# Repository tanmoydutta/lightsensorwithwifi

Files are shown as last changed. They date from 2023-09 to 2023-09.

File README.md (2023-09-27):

<h1>ESP32-C3 based Light sensor</h1>

<h2>Description</h2>
This tiny module is designed around Espressief's ESP32-C3 System On a Chip. Purpose of this module is simple, measure the ambient or incident
light and communicate the reading through the chip's built-in WiFi interface. It uses AMS OSRAM TSL2591 sensor to measure the incident light.

Primary challenge has been to design an RF (Radio Frequency) optimised PCB (Printed Circuit Board) to accommodate this electronics. This designed is optimised for WiFi 2.4GHz and features a
chip antenna (Ignion's NN01-102) to minimize the board size (35mm x 20mm).

The PCB has been designed as per the hardware design guidelines from Espressief with one noticeable deviation on the thickness of the PCB (1.6mm instead of the recommended ~0.8mm)

RF part of the board has been tested with a VNA (Vector Network Analyser) and has been optimized with the help of a matching Pi-network. 
Antenna traces are also designed based upon the datasheet specification and recommended trace pattern.

This hardware has been certified with Open Source Hardware Association


<h2>The Module</h2>
End result of the PCB is a 4 layer design and manufactured with the help of JLC PCB (https://jlcpcb.com) which according to their documentation has a 
dielectric constant of 4.5 for FR-4 type material. 

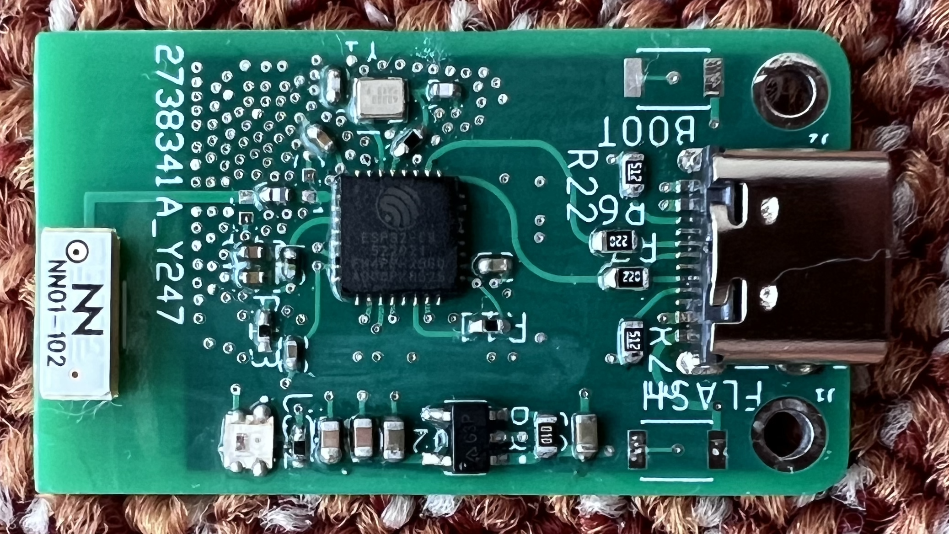
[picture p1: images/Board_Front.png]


The light sensor is mounted on the back side of the board as depicted below -

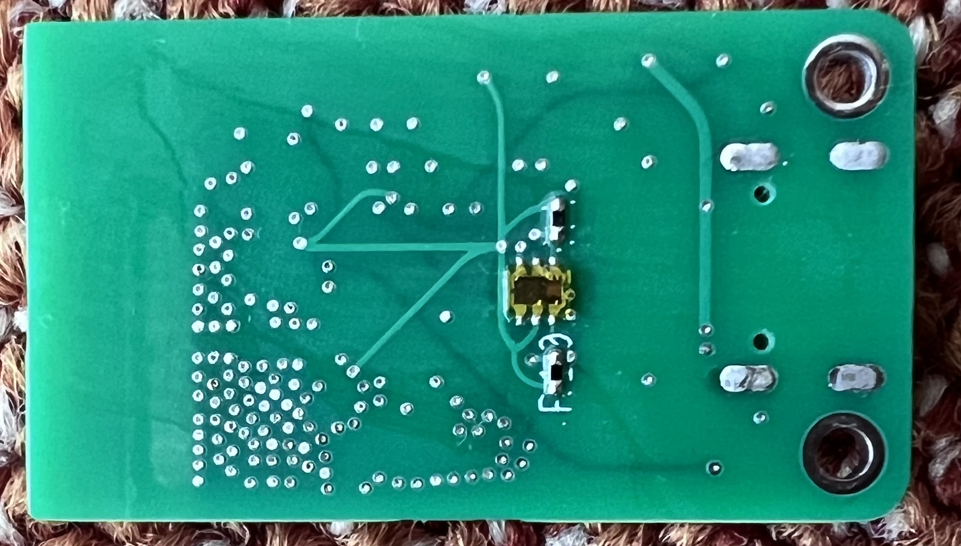
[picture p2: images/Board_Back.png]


Here is a size reference for the end module - 



<h2>Enclosure</h2>
I went ahead and also designed a 3D model for the housing of this module for application - 

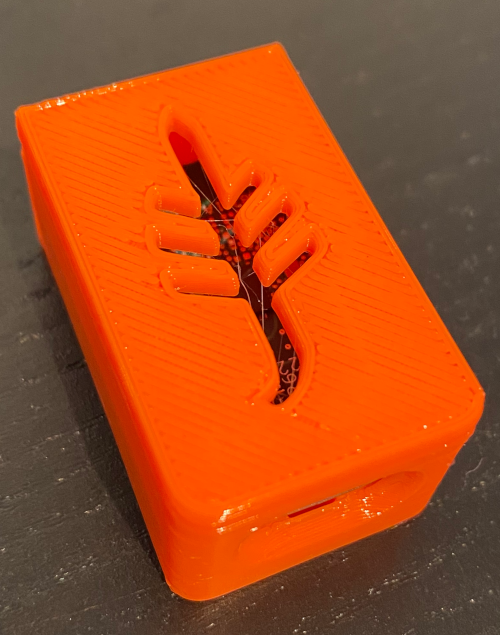
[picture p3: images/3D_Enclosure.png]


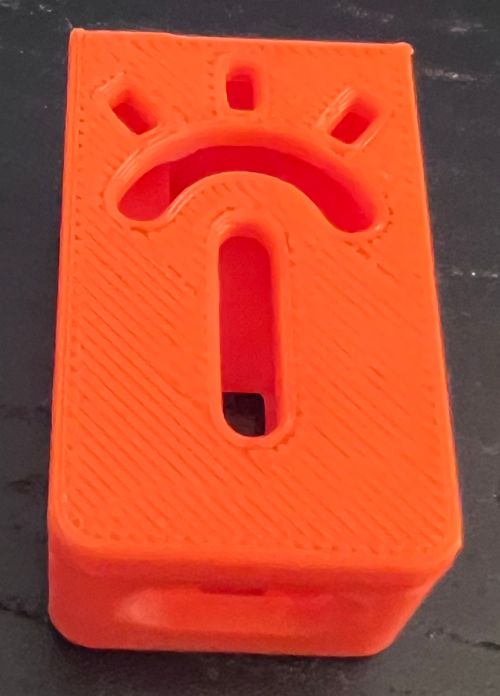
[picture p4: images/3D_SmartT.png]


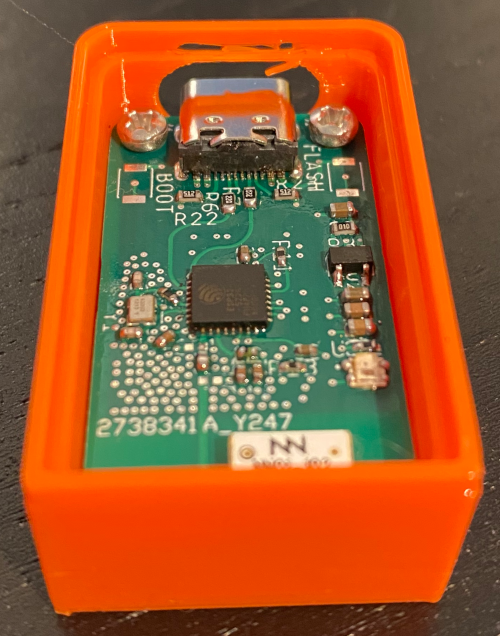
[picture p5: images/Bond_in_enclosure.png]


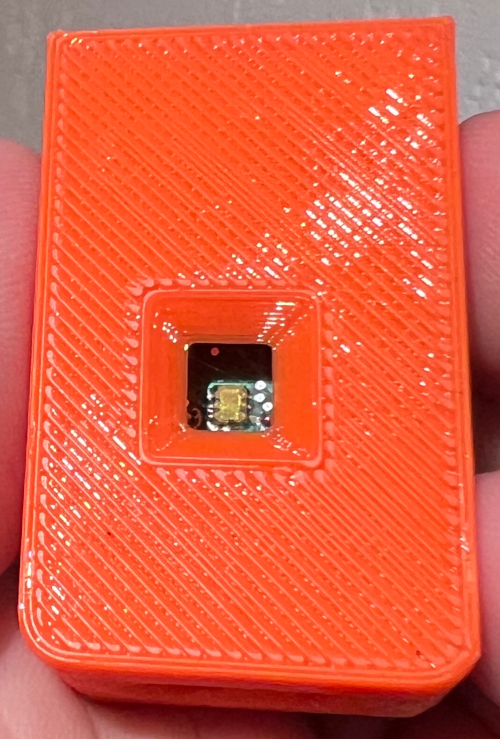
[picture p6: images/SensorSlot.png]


<h2>Programming</h2>
Add your own firmware and code to make use of the built-in sensor and indicator. This module can be programmed using Arduino or ESP-IDF IDE. This module has a 
close resemblance with LOLIN C3 Mini or Adafruit C3 QTPy, hence those core board definitions are compatible with this module.

<h2>Design and Architecture</h2>
Below is the System Context for this module highlighting 
the interfaces and interactions with this module. 

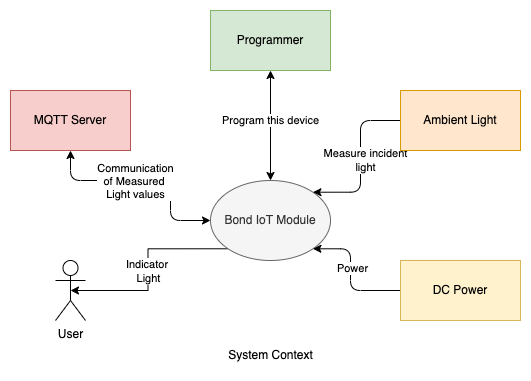
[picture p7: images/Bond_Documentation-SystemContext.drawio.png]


Also a blown up building block of functionality within.

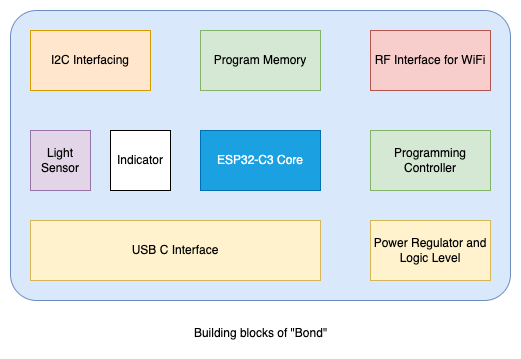
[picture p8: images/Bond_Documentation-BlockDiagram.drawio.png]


<h2>Applications</h2>
One implementation that I personally use this module is for the purpose of controlling the lights on my balcony and eventually also festive lights during Christmas.
Following a possible application diagram -

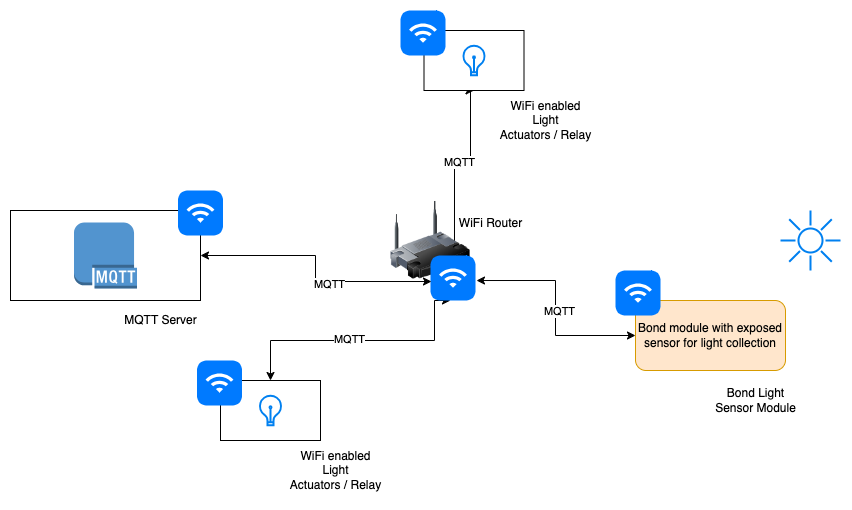
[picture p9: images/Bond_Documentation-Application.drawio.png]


<h2>Open Source Hardware</h2>
This board is an OSHWA approved design: <a href="https://certification.oshwa.org/nl000015.html">NL000015</a>



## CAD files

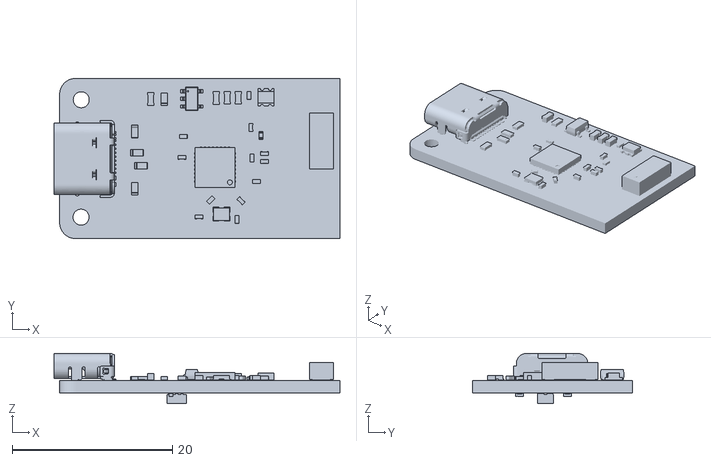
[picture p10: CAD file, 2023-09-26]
3D_Files/Bond.stl
35.7 x 20.0 x 6.26

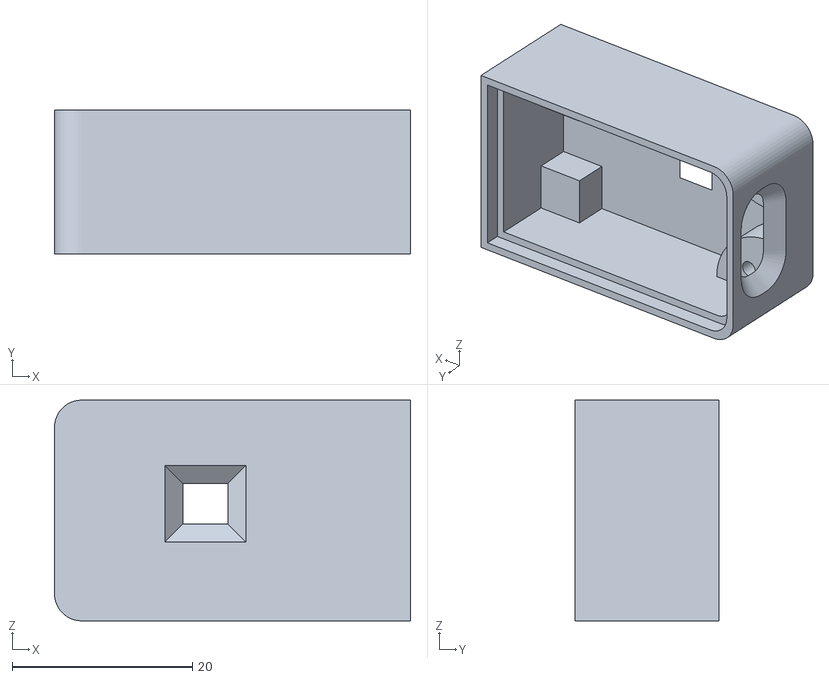
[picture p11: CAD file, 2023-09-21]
3D_Files/BondBox.stl
39.5 x 16.0 x 24.5

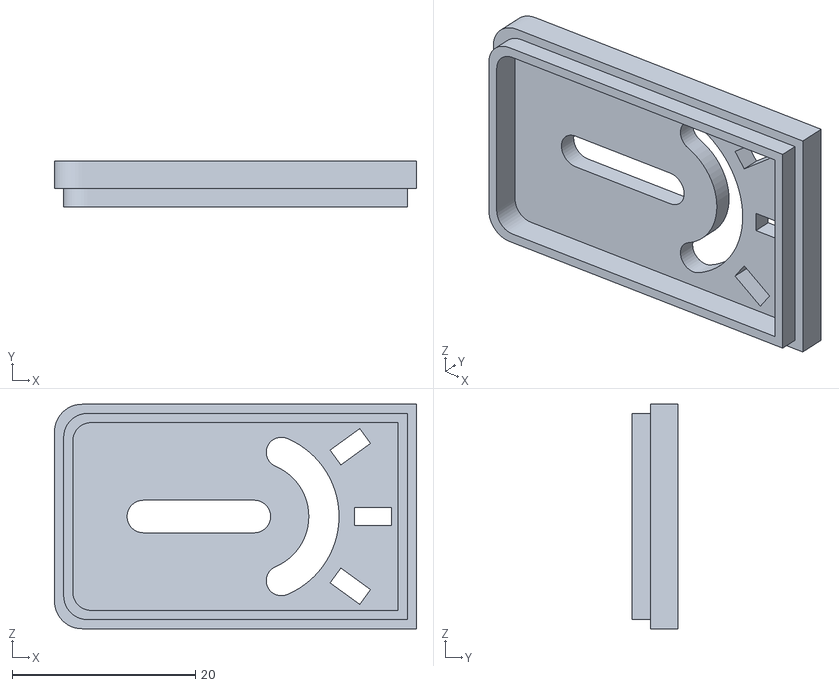
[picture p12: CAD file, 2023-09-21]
3D_Files/BondLidSmartT.stl
39.5 x 5.00 x 24.5

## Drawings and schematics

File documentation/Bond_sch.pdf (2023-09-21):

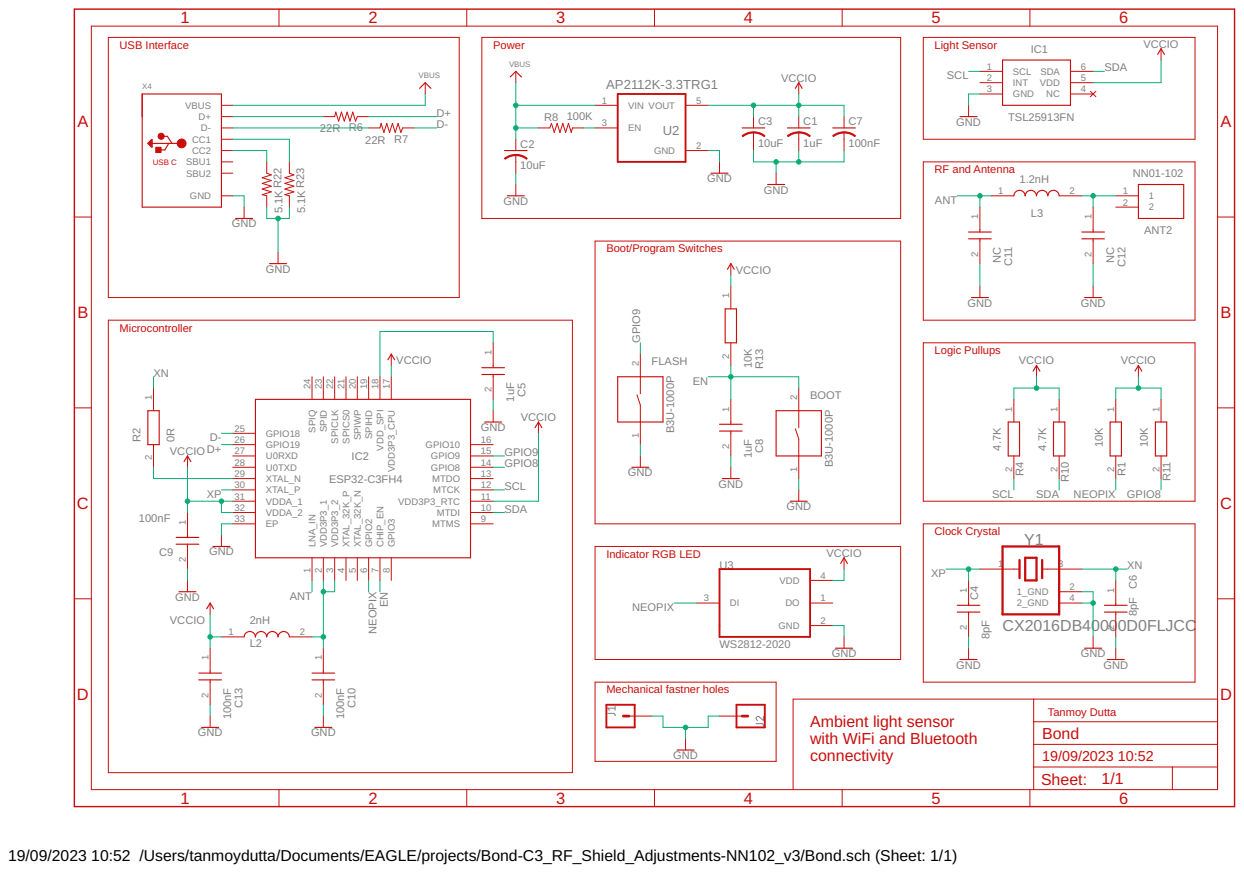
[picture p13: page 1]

Ambient light sensor
with WiFi and Bluetooth
connectivity

19/09/2023 10:52 /Users/tanmoydutta/Documents/EAGLE/projects/Bond-C3_RF_Shield_Adjustments-NN102_v3/Bond.sch (Sheet: 1/1)

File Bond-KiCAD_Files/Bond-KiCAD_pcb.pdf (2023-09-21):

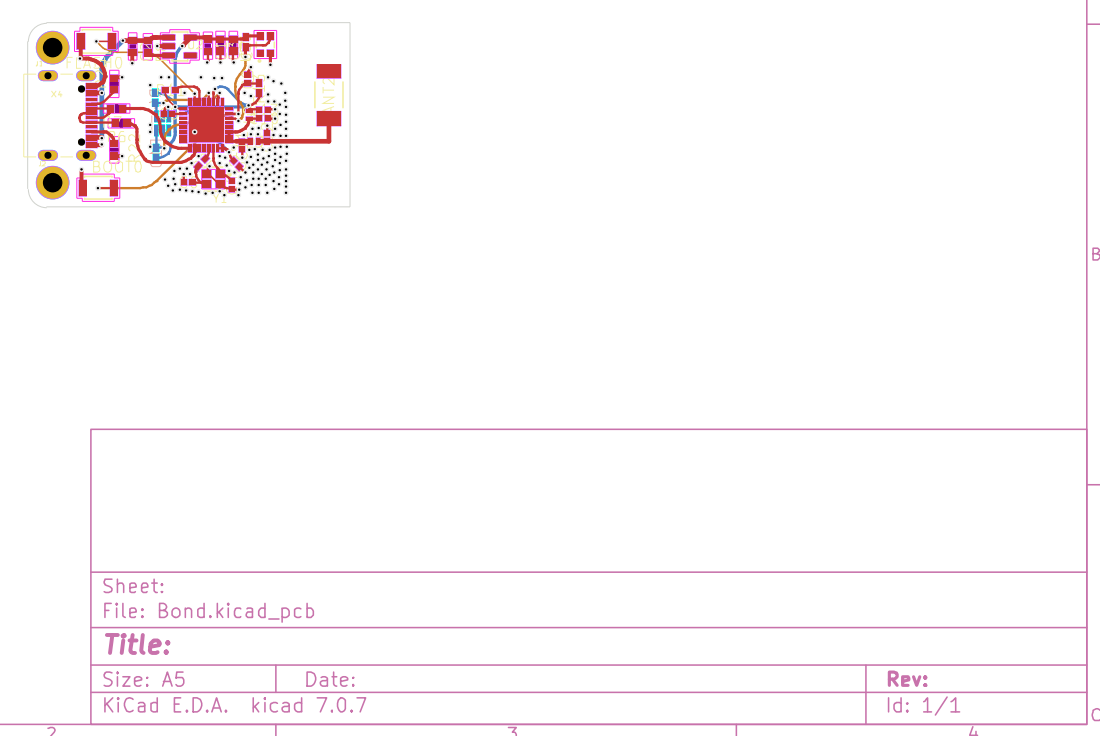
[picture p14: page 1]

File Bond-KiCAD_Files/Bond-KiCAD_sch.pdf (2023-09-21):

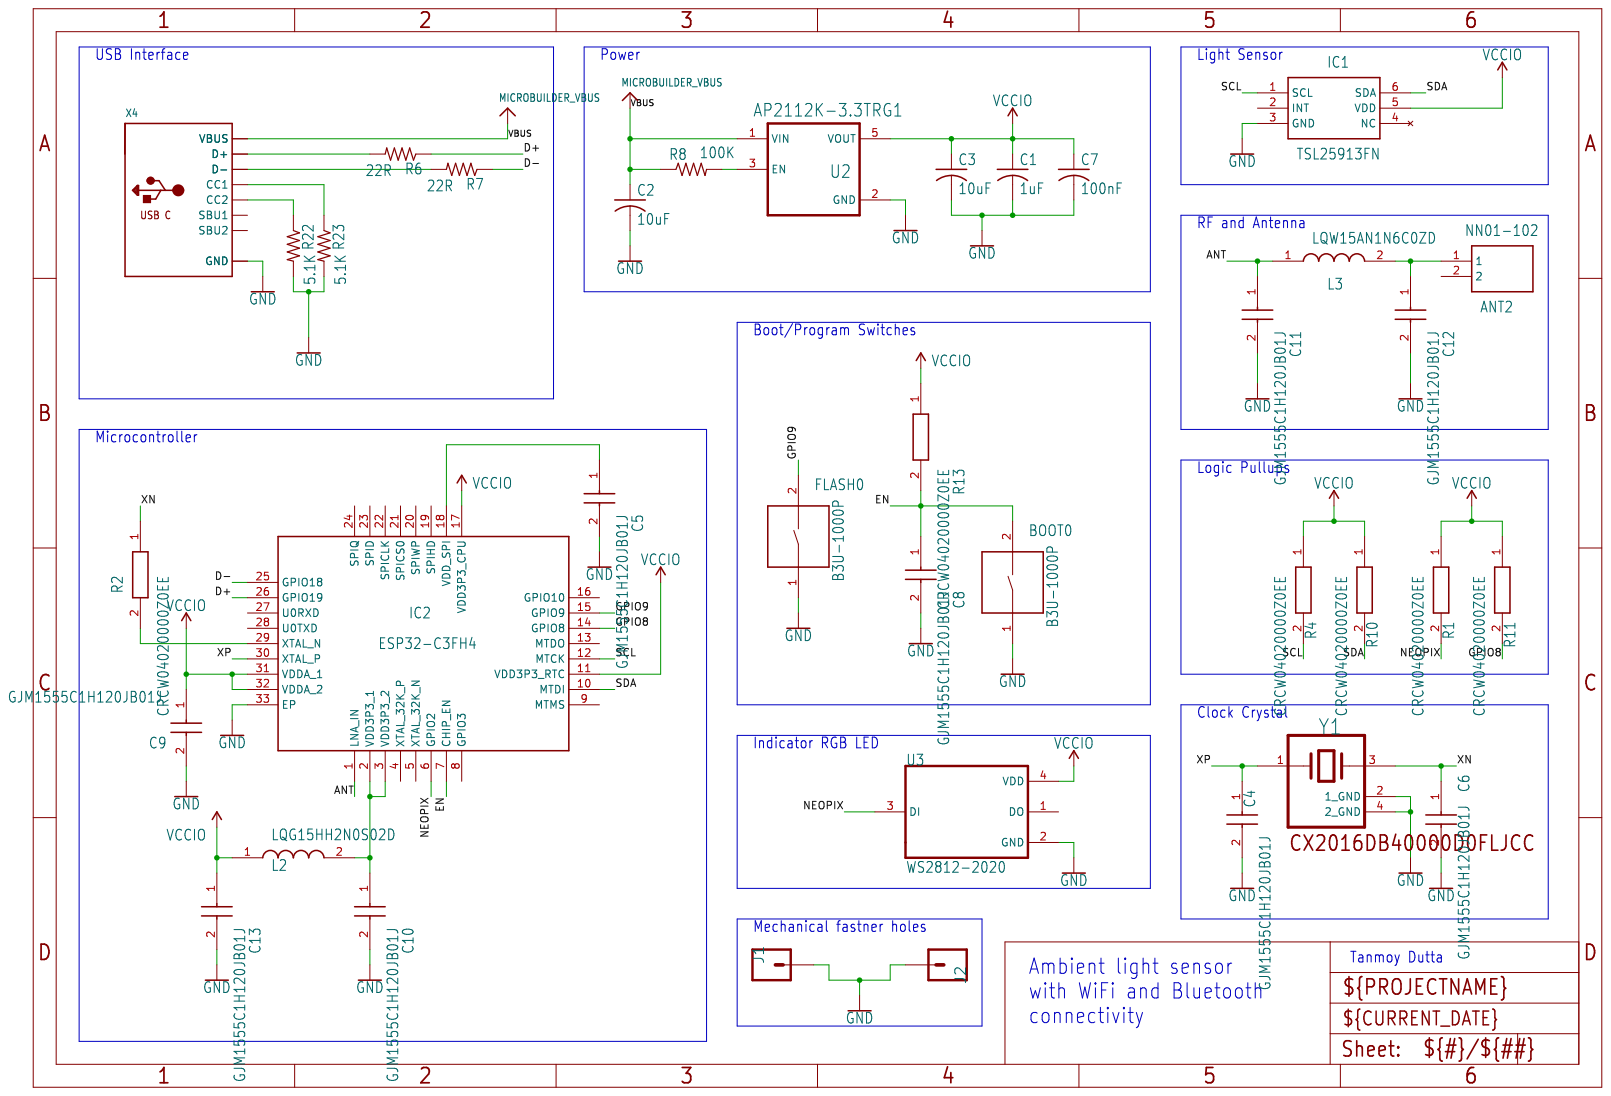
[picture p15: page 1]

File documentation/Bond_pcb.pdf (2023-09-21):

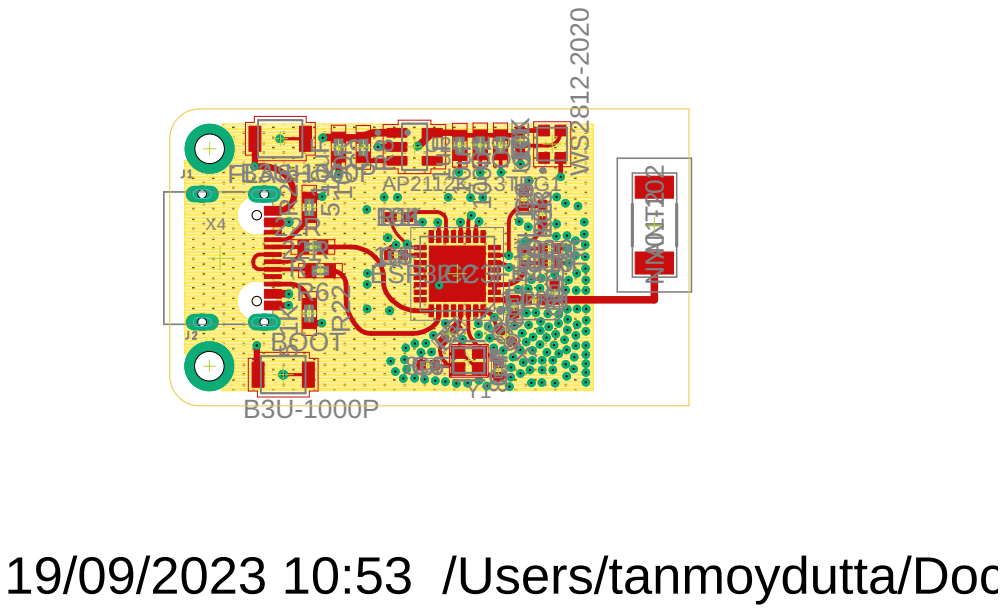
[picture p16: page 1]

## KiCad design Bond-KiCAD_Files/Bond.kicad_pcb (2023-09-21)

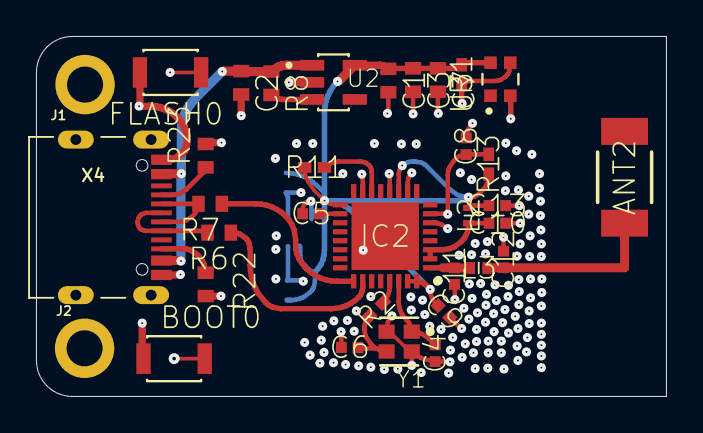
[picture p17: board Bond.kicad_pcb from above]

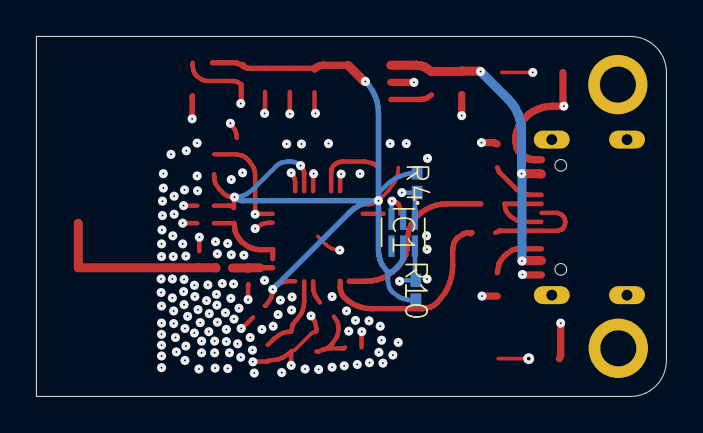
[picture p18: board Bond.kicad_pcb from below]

Board: 4 copper layers, 35.0 x 20.0 mm, 37 parts (3 on the bottom side), 23 nets.

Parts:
ANT2: NN01-102; NN01102
BOOT0: B3U-1000P; SW_B3U-1000P
C1: 1uF; C0402
C2, C3: 10uF; C0402
C4, C6: 8pF; CAPC1005X55N
C5, C8: 1uF; CAPC1005X55N
C7: 100nF; C0402
C9, C10, C13: 100nF; CAPC1005X55N
C11, C12: NC; CAPC1005X55N
FLASH0: B3U-1000P; SW_B3U-1000P
IC1: TSL25913FN
IC2: ESP32-C3FH4; QFN50P500X500X90-33N
J1, J2: 1X01_2MM
L2: 2nH; LQG15WH0N7B02D
L3: 1.2nH; LQW15CNR20J00B
R1, R11, R13: 10K; RESC1005X40N
R2: 0R; RESC1005X40N
R4, R10: 4.7K; RESC1005X40N
R6, R7: 22R; R0402
R8: 100K; R0402
R22, R23: 5.1K; R0402
U2: AP2112K-3.3TRG1; SOT95P285X140-5N
U3: WS2812-2020; LED_WS2812-2020
X4: MICROBUILDER_USB_C_CUSB31-CFM2AX-01-X
Y1: 40MHz; KYOCERA_INTERNATIONAL_INC._ELECTRONIC_COMPONENTS_CX2016DB40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

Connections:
ANT: C11.1, IC2.1, L3.1
D+: IC2.26, R6.1
D-: IC2.25, R7.1
EN: BOOT0.2, C8.1, IC2.7, R13.2
GND: BOOT0.1, C1.2, C2.2, C3.2, C4.2, C5.2, C6.2, C7.2, C8.2, C9.2, C10.2, C11.2, C12.2, C13.2, FLASH0.1, IC1.3, IC2.33, J1.1, J2.1, R22.2, R23.2, U2.2, U3.2, X4.A1B12, X4.B1A12, Y1.2, Y1.4
GPIO8: IC2.14, R11.2
GPIO9: FLASH0.2, IC2.15
unnamed: C5.1, IC2.18
unnamed: ANT2.1, C12.1, L3.2
unnamed: C10.1, IC2.2, IC2.3, L2.2
unnamed: IC2.29, R2.2
unnamed: R22.1, X4.B5
unnamed: R23.1, X4.A5
unnamed: R7.2, X4.A7, X4.B7
unnamed: R6.2, X4.A6, X4.B6
unnamed: R8.2, U2.3
NEOPIX: IC2.6, R1.2, U3.3
SCL: IC1.1, IC2.12, R4.2
SDA: IC1.6, IC2.10, R10.2
VBUS: C2.1, R8.1, U2.1, X4.A4B9, X4.B4A9
VCCIO: C1.1, C3.1, C7.1, C9.1, C13.1, IC1.5, IC2.11, IC2.17, IC2.31, IC2.32, L2.1, R1.1, R4.1, R10.1, R11.1, R13.1, U2.5, U3.4
XN: C6.1, R2.1, Y1.3
XP: C4.1, IC2.30, Y1.1

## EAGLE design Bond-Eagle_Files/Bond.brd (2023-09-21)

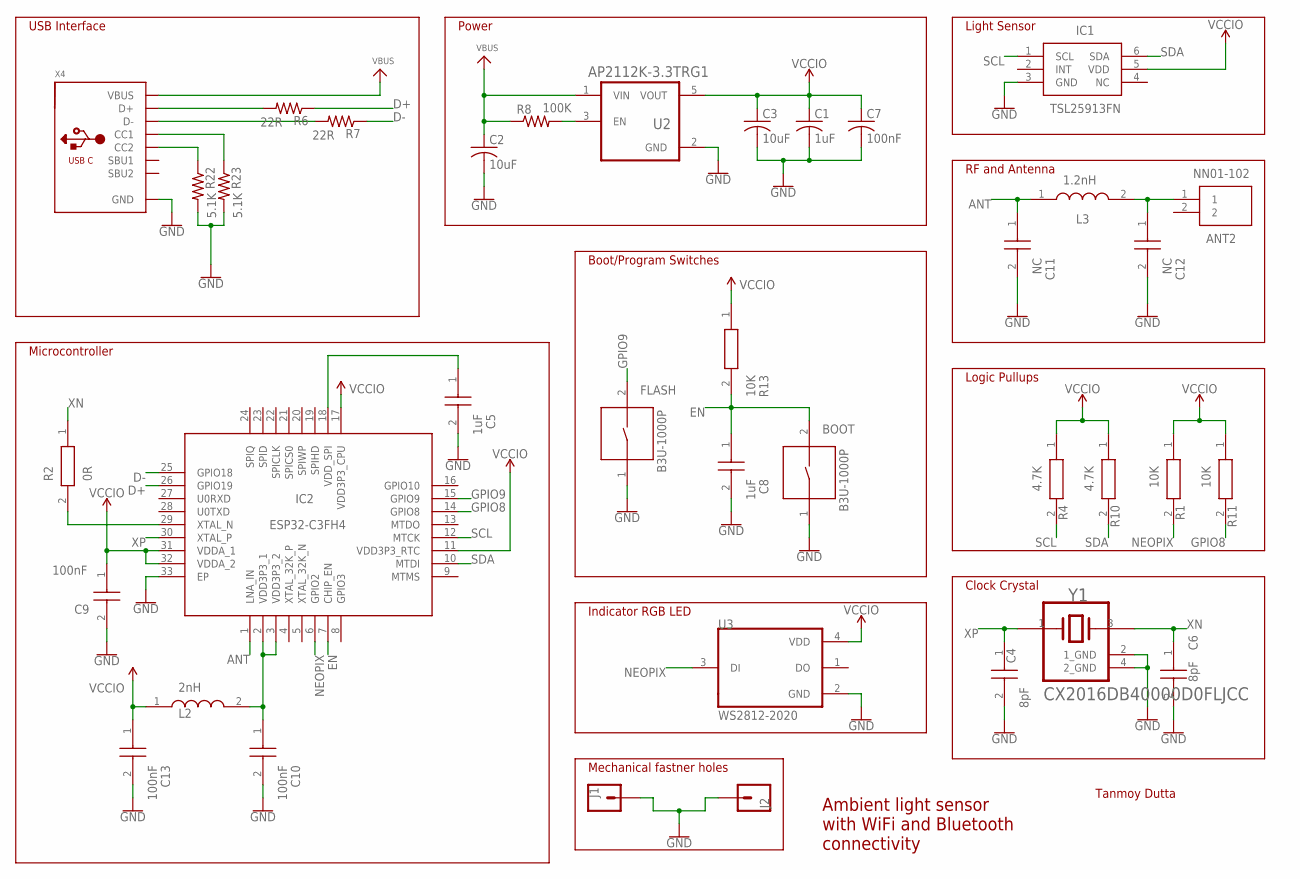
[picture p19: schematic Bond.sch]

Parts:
ANT2: NN01-102; NN01102
BOOT: B3U-1000P; SW_B3U-1000P
C1: 1uF; C0402
C2, C3: 10uF; C0402
C4, C6: 8pF; CAPC1005X55N
C5, C8: 1uF; CAPC1005X55N
C7: 100nF; C0402
C9, C10, C13: 100nF; CAPC1005X55N
C11, C12: NC; CAPC1005X55N
FLASH: B3U-1000P; SW_B3U-1000P
IC1: TSL25913FN
IC2: ESP32-C3FH4; QFN50P500X500X90-33N
J1, J2: CONN_01PTH_2MM; 1X01_2MM
L2: 2nH; LQG15WH0N7B02D
L3: 1.2nH; LQW15CNR20J00B
R1, R11, R13: 10K; RESC1005X40N
R2: 0R; RESC1005X40N
R4, R10: 4.7K; RESC1005X40N
R6, R7: 22R; R0402
R8: 100K; R0402
R22, R23: 5.1K; R0402
U2: AP2112K-3.3TRG1; SOT95P285X140-5N
U3: WS2812-2020; LED_WS2812-2020
X4: MICROBUILDER_USB_C; MICROBUILDER_USB_C_CUSB31-CFM2AX-01-X
Y1: 40MHz; KYOCERA_INTERNATIONAL_INC._ELECTRONIC_COMPONENTS_CX2016DB40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

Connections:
ANT: C11.1, IC2.1 (LNA_IN), L3.1
D+: IC2.26 (GPIO19), R6.1
D-: IC2.25 (GPIO18), R7.1
EN: BOOT.2, C8.1, IC2.7 (CHIP_EN), R13.2
GND: BOOT.1, C1.2, C2.2, C3.2, C4.2, C5.2, C6.2, C7.2, C8.2, C9.2, C10.2, C11.2, C12.2, C13.2, FLASH.1, IC1.3 (GND), IC2.33 (EP), J1.1, J2.1, R22.2, R23.2, U2.2 (GND), U3.2 (GND), X4.A1B12 (GND), X4.B1A12 (GND), Y1.2 (1_GND), Y1.4 (2_GND)
GPIO8: IC2.14 (GPIO8), R11.2
GPIO9: FLASH.2, IC2.15 (GPIO9)
unnamed: C5.1, IC2.18 (VDD_SPI)
unnamed: ANT2.1, C12.1, L3.2
unnamed: C10.1, IC2.2 (VDD3P3_1), IC2.3 (VDD3P3_2), L2.2
unnamed: IC2.29 (XTAL_N), R2.2
unnamed: R22.1, X4.B5 (CC2)
unnamed: R23.1, X4.A5 (CC1)
unnamed: R7.2, X4.A7 (D-), X4.B7 (D-)
unnamed: R6.2, X4.A6 (D+), X4.B6 (D+)
unnamed: R8.2, U2.3 (EN)
NEOPIX: IC2.6 (GPIO2), R1.2, U3.3 (DI)
SCL: IC1.1 (SCL), IC2.12 (MTCK), R4.2
SDA: IC1.6 (SDA), IC2.10 (MTDI), R10.2
VBUS: C2.1, R8.1, U2.1 (VIN), X4.A4B9 (VBUS), X4.B4A9 (VBUS)
VCCIO: C1.1, C3.1, C7.1, C9.1, C13.1, IC1.5 (VDD), IC2.11 (VDD3P3_RTC), IC2.17 (VDD3P3_CPU), IC2.31 (VDDA_1), IC2.32 (VDDA_2), L2.1, R1.1, R4.1, R10.1, R11.1, R13.1, U2.5 (VOUT), U3.4 (VDD)
XN: C6.1, R2.1, Y1.3
XP: C4.1, IC2.30 (XTAL_P), Y1.1

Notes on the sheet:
Microcontroller
USB Interface
Power
Boot/Program Switches
Light Sensor
RF and Antenna
Indicator RGB LED
Mechanical fastner holes
Clock Crystal
Logic Pullups
Ambient light sensor with WiFi and Bluetooth connectivity
Tanmoy Dutta

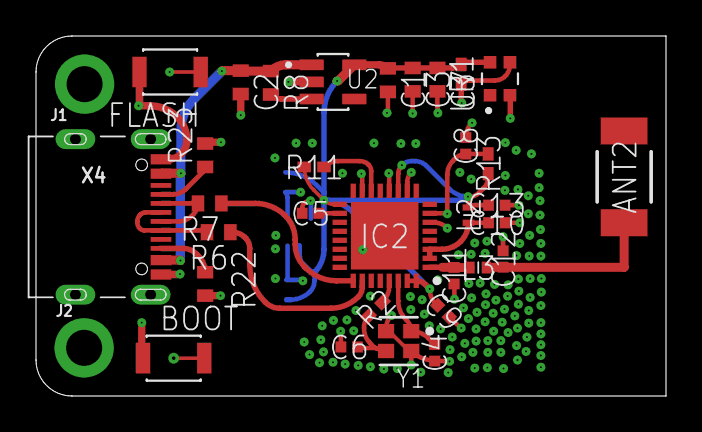
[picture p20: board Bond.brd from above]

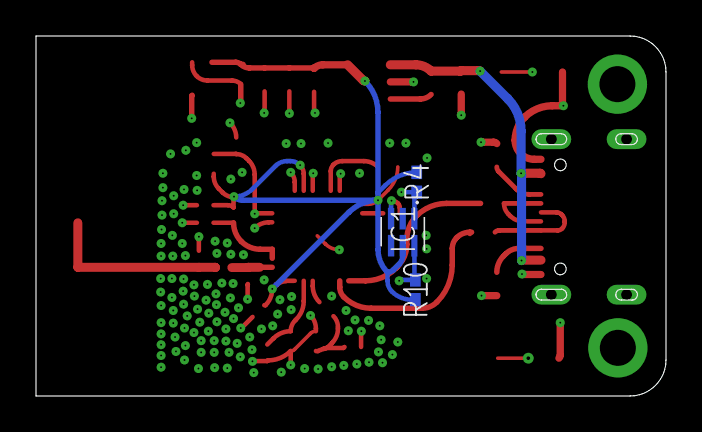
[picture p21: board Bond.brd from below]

Board: 4 copper layers, 35.0 x 20.0 mm, 37 parts (3 on the bottom side), 23 nets.

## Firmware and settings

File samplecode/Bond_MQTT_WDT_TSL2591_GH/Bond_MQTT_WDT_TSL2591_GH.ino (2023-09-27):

/***************************************************
  Adafruit MQTT Library ESP32 Adafruit IO SSL/TLS example

  Use the latest version of the ESP32 Arduino Core:
    https://github.com/espressif/arduino-esp32

  Works great with Adafruit Huzzah32 Feather and Breakout Board:
    https://www.adafruit.com/product/3405
    https://www.adafruit.com/products/4172

  Adafruit invests time and resources providing this open source code,
  please support Adafruit and open-source hardware by purchasing
  products from Adafruit!

  Written by Tony DiCola for Adafruit Industries.
  Modified by Brent Rubell for Adafruit Industries
  MIT license, all text above must be included in any redistribution
 ****************************************************/
#include <WiFi.h>
#include "Adafruit_MQTT.h"
#include "Adafruit_MQTT_Client.h"
#include "esp_system.h"

/* TSL2591 Digital Light Sensor */
/* Dynamic Range: 600M:1 */
/* Maximum Lux: 88K */

#include <Wire.h>
#include <Adafruit_Sensor.h>
#include "Adafruit_TSL2591.h"

// NeoPixel Ring simple sketch (c) 2013 Shae Erisson
// Released under the GPLv3 license to match the rest of the
// Adafruit NeoPixel library

#include <Adafruit_NeoPixel.h>

/******************************************************************/


const int wdtTimeout = 60000;  //time in ms to trigger the watchdog
hw_timer_t *timer = NULL;

void ARDUINO_ISR_ATTR resetModule() {
  ets_printf("reboot\n");
  esp_restart();
}

#define PIN        2
//#define LIGHT_SENSOR   3


unsigned long previousMillis = 0;        // will store last time LED was updated
unsigned long prevMillis = 0;        // will store last time LED was updated

// constants won't change:
const long interval = 1000;           // interval at which to blink (milliseconds)
const long interv = 20000;           // interval at which to blink (milliseconds)

int light = 0;
// How many NeoPixels are attached
#define NUMPIXELS 1

Adafruit_NeoPixel pixels(NUMPIXELS, PIN, NEO_GRB + NEO_KHZ800);


Adafruit_TSL2591 tsl = Adafruit_TSL2591(2591); // pass in a number for the sensor identifier (for your use later)
/************************* WiFi Access Point *********************************/

#define WLAN_SSID       "<WiFi SSID>"
#define WLAN_PASS       "<WiFi Password>"

/************************* Adafruit.io Setup *********************************/

#define MQTT_SERVER      "<MQTT Server IP on the Network>"
#define MQTT_SERVERPORT  1883

/************ Global State (you don't need to change this!) ******************/

// Create an  WiFiClient class to connect to the MQTT server.
WiFiClient client;

// Setup the MQTT client class by passing in the WiFi client and MQTT server and login details.
Adafruit_MQTT_Client mqtt(&client, MQTT_SERVER, MQTT_SERVERPORT);

/****************************** Feeds ***************************************/

Adafruit_MQTT_Publish lightIntensity = Adafruit_MQTT_Publish(&mqtt,  "/feeds/message/ambient/light");


/*************************** Sketch Code ************************************/

/**
Name: Configure Sensor TSL2591
Description: Set gain and integration time with sensor

*/
void configureSensor(void) {
  // You can change the gain on the fly, to adapt to brighter/dimmer light situations
  tsl.setGain(TSL2591_GAIN_LOW);    // 1x gain (bright light)
  //tsl.setGain(TSL2591_GAIN_MED);      // 25x gain
  //tsl.setGain(TSL2591_GAIN_HIGH);   // 428x gain
  
  // Changing the integration time gives you a longer time over which to sense light
  // longer timelines are slower, but are good in very low light situtations!
  tsl.setTiming(TSL2591_INTEGRATIONTIME_100MS);  // shortest integration time (bright light)
  // tsl.setTiming(TSL2591_INTEGRATIONTIME_200MS);
  // tsl.setTiming(TSL2591_INTEGRATIONTIME_300MS);
  // tsl.setTiming(TSL2591_INTEGRATIONTIME_400MS);
  // tsl.setTiming(TSL2591_INTEGRATIONTIME_500MS);
  // tsl.setTiming(TSL2591_INTEGRATIONTIME_600MS);  // longest integration time (dim light)


}

/**
Name: Initialize NeoPixel
Description: Set brightness

*/
void _init_heartbeat() {
  pixels.setBrightness(255);
}


/**
Name: Heartbeat functionality
Description: Blink the Neo Pixel on specific color and duration

*/
void heartbeat() {
  pixels.clear(); // Set all pixel colors to 'off'
  pixels.setPixelColor(0, pixels.Color(150, 0, 150));
  pixels.show();
  delay(50);

  pixels.clear(); // Set all pixel colors to 'off'
  pixels.setPixelColor(0, pixels.Color(0, 0, 0));
  pixels.show();
  //delay(5000);
}

/**
Name: Setup
Description: Centralised initial configuration

*/
void setup() {
  Serial.begin(115200);
  delay(10);

  if (tsl.begin()) {
    Serial.println(F("Found a TSL2591 sensor"));
  } else {
    Serial.println(F("No sensor found ... check your wiring?"));
    while (1);
  }
  /* Configure the sensor */
  configureSensor();

  timer = timerBegin(0, 80, true);                  //timer 0, div 80
  timerAttachInterrupt(timer, &resetModule, true);  //attach callback
  timerAlarmWrite(timer, wdtTimeout * 1000, false); //set time in us
  timerAlarmEnable(timer);                          //enable interrupt

  //pinMode(LED_PIN, OUTPUT);
  
  // Connect to WiFi access point.
  Serial.println(); Serial.println();
  Serial.print("Connecting to ");
  Serial.println(WLAN_SSID);

  WiFi.begin(WLAN_SSID, WLAN_PASS);
  while (WiFi.status() != WL_CONNECTED) {
    delay(500);
    Serial.print(".");
  }
  Serial.println();

  Serial.println("WiFi connected");
  Serial.println("IP address: "); Serial.println(WiFi.localIP());

  pixels.begin();
  _init_heartbeat();
  MQTT_connect();
  sendLightData();

}

/**
Name: Main loop
Description: Code orchestration that run in circles

*/
void loop() {
  
  // Ensure the connection to the MQTT server is alive (this will make the first
  // connection and automatically reconnect when disconnected).  See the MQTT_connect
  // function definition further below.
  MQTT_connect();

  // this is our 'wait for incoming subscription packets and callback em' busy subloop
  // try to spend your time here:
  mqtt.processPackets(10000);
  
  // ping the server to keep the mqtt connection alive
  // NOT required if you are publishing once every KEEPALIVE seconds
  
  if(! mqtt.ping()) {
    mqtt.disconnect();
  }

  unsigned long currentMillis = millis();

  if (currentMillis - prevMillis >= interv) {
    // save the last time you blinked the LED
    prevMillis = currentMillis;

    timerWrite(timer, 0); //reset timer (feed watchdog)
    
    sendLightData();
  }
}


/**
Name: MQTT Publish
Description: Read sensor and send MQTT packet with data

*/
void sendLightData() {
  light = tsl.getLuminosity(TSL2591_VISIBLE);//analogRead(LIGHT_SENSOR);
  Serial.print("Light: ");Serial.println(light);
  

  String dat = "";

  //memset(dat, 0, sizeof(1110));

  dat += "{\"l\" : ";
  dat += String(light);

  dat += "}";
  
  Serial.println(dat);
  int z = dat.length();
  Serial.print("Size of Data : "); Serial.println(z); 
  
  char c[z+1];
  dat.toCharArray(c, z+1);

  Serial.print("c=");
  Serial.println(c);
  
  uint8_t a[z+1];
  for (int i = 0; i <= z; i++) {
    a[i] = (uint8_t)c[i];//Serial.print(interim[i]);
  }


  lightIntensity.publish(c);
}

/**
Name: MQTT Connect
Description: Function to connect and reconnect as necessary to the MQTT server.
Should be called in the loop function and it will take care if connecting.
*/
void MQTT_connect() {
  int8_t ret;

  // Stop if already connected.
  if (mqtt.connected()) {
    ledCheck();
    return;
  }

  Serial.print("Connecting to MQTT... ");

  uint8_t retries = 3;
  while ((ret = mqtt.connect()) != 0) { // connect will return 0 for connected
       Serial.println(mqtt.connectErrorString(ret));
       Serial.println("Retrying MQTT connection in 10 seconds...");
       mqtt.disconnect();
       delay(10000);  // wait 10 seconds
       retries--;
       if (retries == 0) {
         // basically die and wait for WDT to reset me
         while (1);
       }
  }
  Serial.println("MQTT Connected!");
}


/**
Name: Blink Neo Pixel
Description: Blink the indicator for operation of the unit through heartbeat

*/
void ledCheck() {
  unsigned long currentMillis = millis();

  if (currentMillis - previousMillis >= interval) {
    // save the last time you blinked the LED
    previousMillis = currentMillis;

    heartbeat();
  }  
}

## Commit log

2023-09-21 Adding Bond files
    [Bond.brd, Bond.kicad_pcb, Bond.kicad_sch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]
2023-09-21 Adding Bond in enclosure image
2023-09-21 Adding Sensor slot image
2023-09-26 Adding correct 3D file for the PCB
    [Bond.stl]
2023-09-27 Adding a sample source code to operate the unit

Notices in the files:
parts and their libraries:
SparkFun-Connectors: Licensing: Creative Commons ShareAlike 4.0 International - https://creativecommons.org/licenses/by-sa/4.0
